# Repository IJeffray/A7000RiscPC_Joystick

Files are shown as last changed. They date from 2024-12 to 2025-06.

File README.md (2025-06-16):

# Acorn A7000 / RiscPC Joystick 'NIC'

April 2025

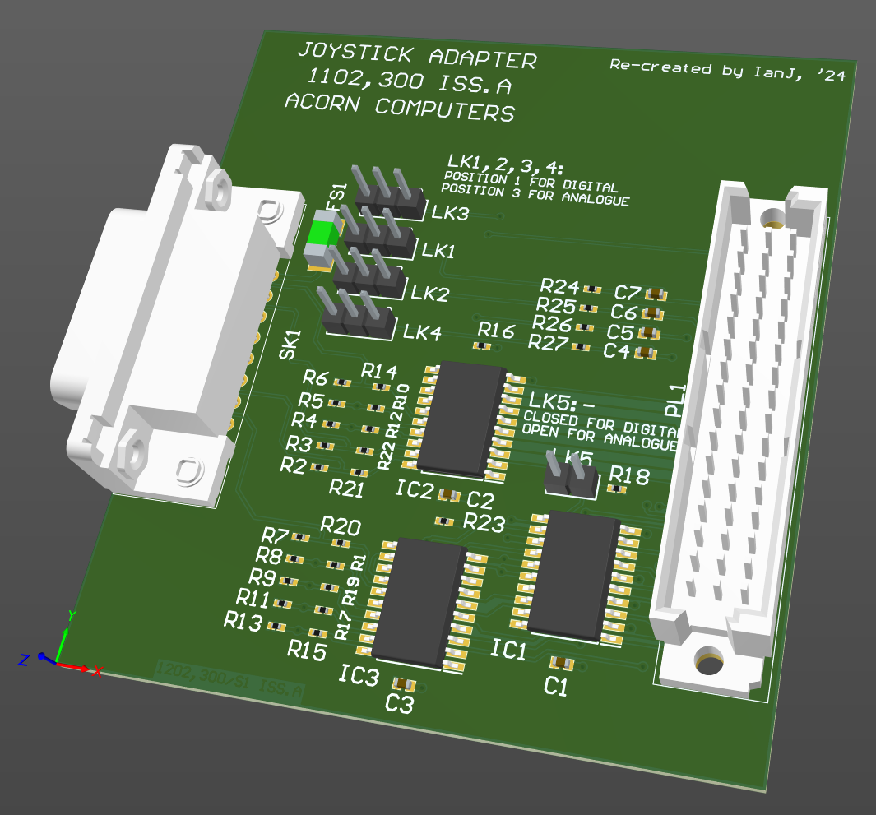
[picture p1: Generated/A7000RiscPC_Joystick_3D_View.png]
3D View


A re-creation of the official (but not commercially released?) Acorn "1102,300" Joystick Adapter, for Acorn A7000 and RiscPC machines NIC slot.

On A7000 (only), this can support analog joysticks, as the ARM7500 SoC includes appropriate analog to digital converters, not found in the RiscPC.

This has been built and tested and appears to work as expected for digital inputs, however one half of each analog axis appears inverted - this may be a software issue, however has yet to be fully investigated.

[PDF schematic](Generated/A7000RiscPC_Joystick.pdf)

## Licence

No warranty is provided, and this work is used at your own risk.  

Licenced as CC BY-SA 4.0

Copyright 2025 Ian Jeffray

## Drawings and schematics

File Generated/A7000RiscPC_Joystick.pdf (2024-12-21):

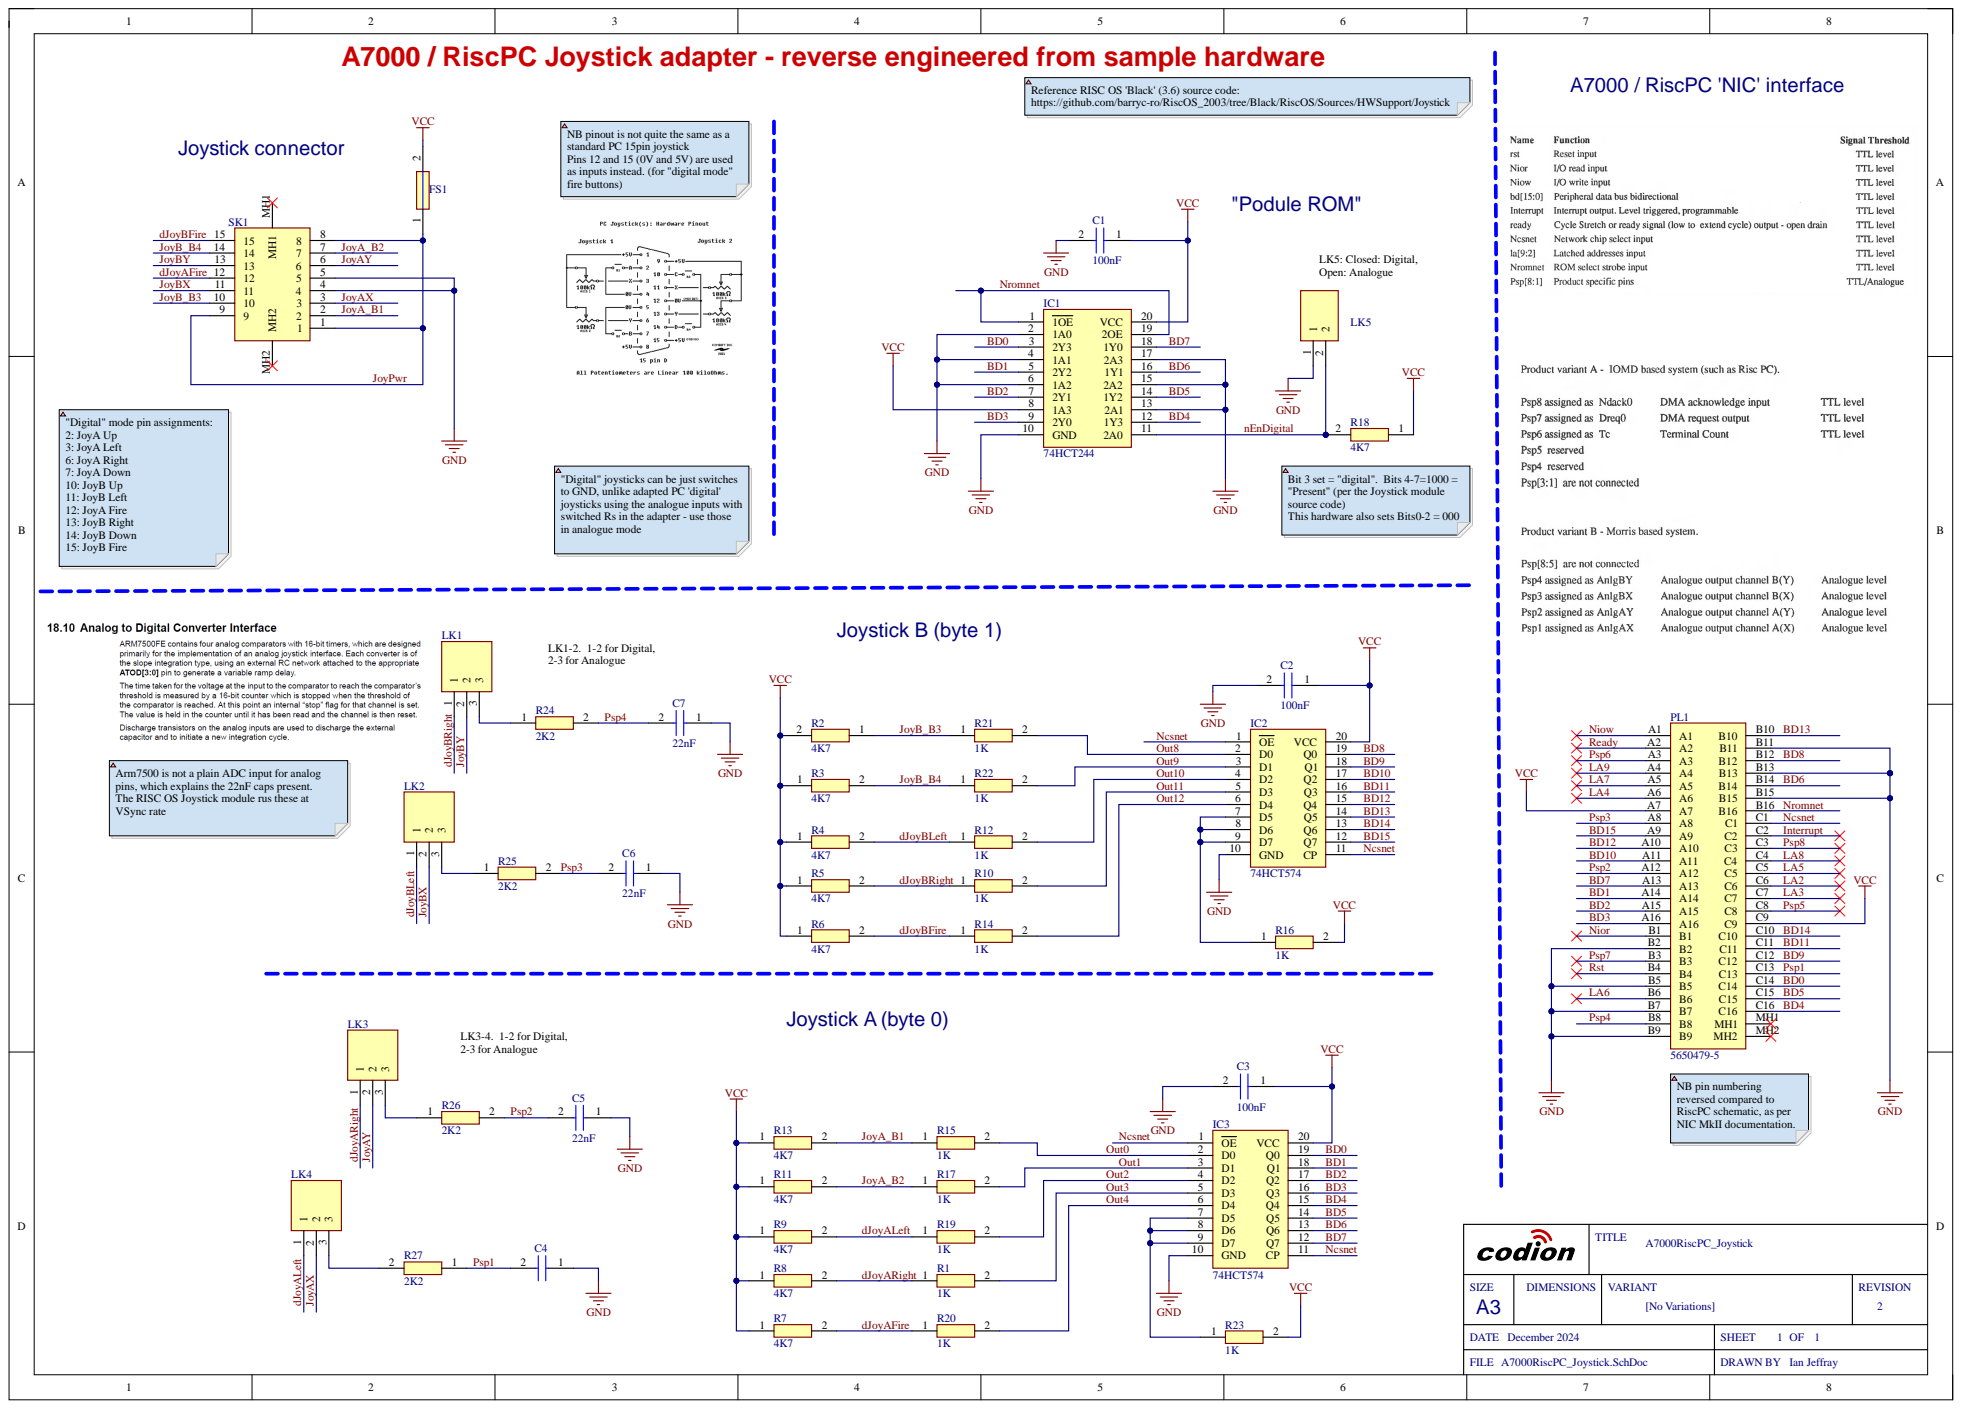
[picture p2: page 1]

A7000 / RiscPC Joystick adapter - reverse engineered from sample hardware

Reference RISC OS 'Black' (3.6) source code:
https://github.com/barryc-ro/RiscOS_2003/tree/Black/RiscOS/Sources/HWSupport/Joystick

NB pinout is not quite the same as a
standard PC 15pin joystick
Pins 12 and 15 (0V and 5V) are used
as inputs instead. (for "digital mode"
fire buttons)

"Digital" mode pin assignments:
2: JoyA Up
3: JoyA Left
6: JoyA Right
7: JoyA Down
10: JoyB Up
11: JoyB Left
12: JoyA Fire
13: JoyB Right
14: JoyB Down
15: JoyB Fire

"Digital" joysticks can be just switches
to GND, unlike adapted PC 'digital'
joysticks using the analogue inputs with
switched Rs in the adapter - use those
in analogue mode

Bit 3 set = "digital". Bits 4-7=1000 =
"Present" (per the Joystick module
source code)
This hardware also sets Bits0-2 = 000

Arm7500 is not a plain ADC input for analog
pins, which explains the 22nF caps present.
The RISC OS Joystick module rus these at
VSync rate

D7 9 | BD15
GND 10

NB pin numbering
reversed compared to
RiscPC schematic, as per
NIC MkII documentation.

D5 7
D6 8

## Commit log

2024-06-04 Initial WIP - basic component entry and placement.
    [A7000RiscPC_Joystick.PcbDoc, A7000RiscPC_Joystick.PrjPcb, A7000RiscPC_Joystick.SchDoc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]
2024-06-07 More WIP - most signals identified now
    [A7000RiscPC_Joystick.PcbDoc, A7000RiscPC_Joystick.SchDoc]
2024-06-08 Completed the reverse engineering at schematic level, original warts and all.
    [A7000RiscPC_Joystick.PcbDoc, A7000RiscPC_Joystick.PrjPcb, A7000RiscPC_Joystick.SchDoc]
2024-12-12 Swap IC1/C3 parts as is obviously build error on original. Swap Rs around to make more sense, as is obviously build error on original. Do some routing.
    [A7000RiscPC_Joystick.PcbDoc, A7000RiscPC_Joystick.PrjPcb, A7000RiscPC_Joystick.SchDoc]
2024-12-21 Updated schematic to match reality that will actually work, not as Acorn built the sample. Corrected clock input to the flipflops. Routing complete - mostly as per Acorn's layout, with some small twe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
    [A7000RiscPC_Joystick.PcbDoc, A7000RiscPC_Joystick.PrjPcb, A7000RiscPC_Joystick.SchDoc]
2025-04-14 Minor cleanups and rule clarifications. Outjob still locks up Altium.
    [A7000RiscPC_Joystick.PcbDoc, A7000RiscPC_Joystick.PrjPcb]
2025-04-14 Disable 'software arcs' during gerber generation to work around Altium bug
2025-04-21 Update project status. Tweaks to output job files.
    [A7000RiscPC_Joystick.PcbDoc, A7000RiscPC_Joystick.PrjPcb]
2025-06-16 Update build status. Add 3D view of PCB.
